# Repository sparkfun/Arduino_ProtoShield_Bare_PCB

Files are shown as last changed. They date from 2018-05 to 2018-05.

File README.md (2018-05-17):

SparkFun Arduino ProtoShield - Bare PCB
=======================================

<table class="table table-hover table-striped table-bordered">
  <tr align="center">
   <td><a href="https://cdn.sparkfun.com//assets/parts/1/1/4/1/1/13819-SparkFun_ProtoShield-01.jpg">SparkFun Arduino ProtoShield - Bare PCB</a></td>
   <td><a href="https://cdn.sparkfun.com//assets/parts/1/1/4/1/2/13820-SparkFun_ProtoShield_Kit-01.jpg">SparkFun ProtoShield Kit</a></td>
  </tr>
  <tr align="center">
    <td>SparkFun Arduino ProtoShield - Bare PCB [ <a href="https://www.sparkfun.com/products/13819">DEV-13819</a> ]</td>
    <td>SparkFun ProtoShield Kit [ <a href="https://www.sparkfun.com/products/13820">DEV-13820</a> ]</td>
  </tr>
</table>

The SparkFun Arduino ProtoShield is a bare PCB with no attached or included parts that lets you customize your own Arduino shield using whatever circuit you can come up with! You will even be able to test your circuit or project to make sure everything is working the way it should! The SparkFun Arduino ProtoShield is based off the Arduino R3’s footprint that allows you to easily incorporate it with favorite Arduino-based device.

Repository Contents
-------------------
* **/Firmware** - Example code used in the hookup guide.
* **/Hardware** - All Eagle design files (.brd, .sch)
* **/Production** - All Eagle design files (.brd, .sch)

Documentation
--------------
* **[Hookup Guide](https://learn.sparkfun.com/tutorials/sparkfun-arduino-protoshield-hookup-guide)** - Basic hookup guide for the SparkFun Arduino ProtoShield v40.
* _**[Quickstart Guide (RETIRED)](https://learn.sparkfun.com/tutorials/arduino-protoshield-quickstart-guide)** - Basic quickstart guide for the SparkFun Arduino ProtoShield v25._

Product Versions
----------------
* [DEV-13819](https://www.sparkfun.com/products/13819) - Bare pcb.
* [DEV-13820](https://www.sparkfun.com/products/13820) - Protoshield Kit. Bare pcb, plus stackable headers, indicator LEDs, push buttons, and resistors.
* _[DEV-11665 (RETIRED)](https://www.sparkfun.com/products/11665) - Bare pcb._
* _[DEV-07914 (RETIRED)](https://www.sparkfun.com/products/7914) - Protoshield Kit. Bare pcb plus stackable headers, indicator LEDs, push buttons and resistors._

Version History
---------------
* [V_4.0F2.0](https://github.com/sparkfun/Arduino_ProtoShield_Bare_PCB/releases/tag/V_4.0F2.0) - Revision v4.0 with updated example code.
* [V_2.5F1.0](https://github.com/sparkfun/Arduino_ProtoShield_Bare_PCB/releases/tag/V_2.5F1.0) - Initial release with example code from quickstart guide 
* [V_2.5](https://github.com/sparkfun/Arduino_ProtoShield_Bare_PCB/releases/tag/V_2.5) - Initial release

License Information
-------------------

This product is _**open source**_! 

Please review the LICENSE.md file for license information. 

If you have any questions or concerns on licensing, please contact techsupport@sparkfun.com.

Distributed as-is; no warranty is given.

- Your friends at SparkFun.

_<COLLABORATION CREDIT>_

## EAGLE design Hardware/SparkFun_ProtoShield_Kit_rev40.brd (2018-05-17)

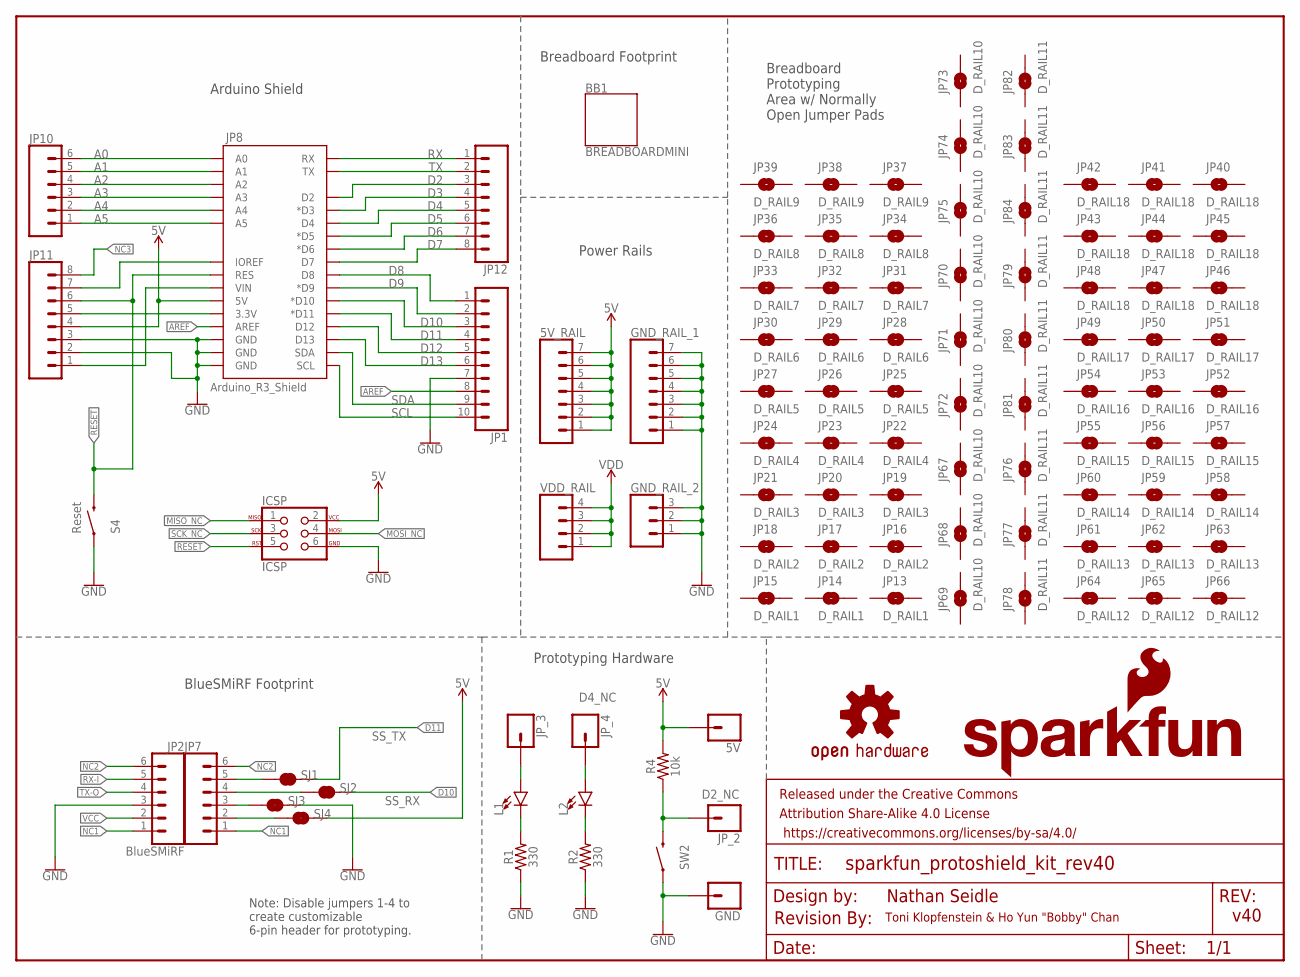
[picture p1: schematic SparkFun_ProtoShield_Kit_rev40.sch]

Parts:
5V: CONN_01; 1X01
5V_RAIL: CONN_07NO_SILK; 1X07_NO_SILK
BB1: BREADBOARDMINI; BREADBOARD-MINI
FRAME1: FRAME-LETTER; CREATIVE_COMMONS
GND: CONN_01; 1X01
GND_RAIL_1: CONN_07NO_SILK; 1X07_NO_SILK
GND_RAIL_2: CONN_031X03_NO_SILK; 1X03_NO_SILK
ICSP: ICSP; 2X3
JP1: CONN_10"; 1X10
JP2: BlueSMiRF; 1X06
JP7, JP10: CONN_06SILK_FEMALE_PTH; 1X06
JP8: ARDUINO_R3_SHIELDR3_PROTO_SHIELD; UNO_R3_PROTO_SHIELD
JP11, JP12: CONN_08"; 1X08
JP13, JP14, JP15: D_RAIL1; SMT-JUMPER_2_NO_NO-SILK
JP16, JP17, JP18: D_RAIL2; SMT-JUMPER_2_NO_NO-SILK
JP19, JP20, JP21: D_RAIL3; SMT-JUMPER_2_NO_NO-SILK
JP22, JP23, JP24: D_RAIL4; SMT-JUMPER_2_NO_NO-SILK
JP25, JP26, JP27: D_RAIL5; SMT-JUMPER_2_NO_NO-SILK
JP28, JP29, JP30: D_RAIL6; SMT-JUMPER_2_NO_NO-SILK
JP31, JP32, JP33: D_RAIL7; SMT-JUMPER_2_NO_NO-SILK
JP34, JP35, JP36: D_RAIL8; SMT-JUMPER_2_NO_NO-SILK
JP37, JP38, JP39: D_RAIL9; SMT-JUMPER_2_NO_NO-SILK
JP40, JP41, JP42, JP43, JP44, JP45, JP46, JP47, JP48: D_RAIL18; SMT-JUMPER_2_NO_NO-SILK
JP49, JP50, JP51: D_RAIL17; SMT-JUMPER_2_NO_NO-SILK
JP52, JP53, JP54: D_RAIL16; SMT-JUMPER_2_NO_NO-SILK
JP55, JP56, JP57: D_RAIL15; SMT-JUMPER_2_NO_NO-SILK
JP58, JP59, JP60: D_RAIL14; SMT-JUMPER_2_NO_NO-SILK
JP61, JP62, JP63: D_RAIL13; SMT-JUMPER_2_NO_NO-SILK
JP64, JP65, JP66: D_RAIL12; SMT-JUMPER_2_NO_NO-SILK
JP67, JP68, JP69, JP70, JP71, JP72, JP73, JP74, JP75: D_RAIL10; SMT-JUMPER_2_NO_NO-SILK
JP76, JP77, JP78, JP79, JP80, JP81, JP82, JP83, JP84: D_RAIL11; SMT-JUMPER_2_NO_NO-SILK
JP_2, JP_3, JP_4: CONN_01; 1X01
L1, L2: LED3MM; LED_3MM
LOGO1: OSHW-LOGOS; OSHW-LOGO-S
R1, R2: 330; AXIAL-0.3
R4: 10k; AXIAL-0.3
S4: MOMENTARY-SWITCH-SPST-PTH-6.0MM; TACTILE_SWITCH_PTH_6.0MM
SJ1, SJ2, SJ3, SJ4: JUMPER-SMT_2_NC_TRACE_SILK; SMT-JUMPER_2_NC_TRACE_SILK
SW2: MOMENTARY-SWITCH-SPST-PTH-6.0MM; TACTILE_SWITCH_PTH_6.0MM
U$1: SFE_LOGO_NAME_FLAME.1_INCH; SFE_LOGO_NAME_FLAME_.1
U$2: REVISION
VDD_RAIL: CONN_041X04_NO_SILK; 1X04_NO_SILK

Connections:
3.3: JP8.3.3V, JP11.5
5V: 5V.1, 5V_RAIL.1, 5V_RAIL.2, 5V_RAIL.3, 5V_RAIL.4, 5V_RAIL.5, 5V_RAIL.6, 5V_RAIL.7, ICSP.2, JP8.5V, JP11.4, R4.P$2 (2), SJ4.2
A1: JP8.A1, JP10.5
A2: JP8.A2, JP10.4
A5: JP8.A5, JP10.1
AREF: JP1.8, JP8.AREF
D2: JP8.D2, JP12.3
D2_NC: JP_2.1, R4.P$1 (1), SW2.3 (2)
D3: JP8.D3 (*D3), JP12.4
D4: JP8.D4, JP12.5
D5: JP8.D5 (*D5), JP12.6
D6: JP8.D6 (*D6), JP12.7
D7: JP8.D7, JP12.8
D8: JP1.1, JP8.D8
D9: JP1.2, JP8.D9 (*D9)
D10: JP1.3, JP8.D10 (*D10), SJ2.2
D11: JP1.4, JP8.D11 (*D11), SJ1.2
D12: JP1.5, JP8.D12
D13: JP1.6, JP8.D13
GND: GND.1, GND_RAIL_1.1, GND_RAIL_1.2, GND_RAIL_1.3, GND_RAIL_1.4, GND_RAIL_1.5, GND_RAIL_1.6, GND_RAIL_1.7, GND_RAIL_2.1, GND_RAIL_2.2, GND_RAIL_2.3, ICSP.6, JP1.7, JP2.3, JP7.3, JP8.GND@0 (GND), JP8.GND@1 (GND), JP8.GND@2 (GND), JP11.2, JP11.3, R1.P$1 (1), R2.P$1 (1), S4.1, SJ3.1, SJ3.2, SW2.1
JP3: JP_3.1, L1.A
JP4: JP_4.1, L2.A
MISO_NC: ICSP.1
MOSI_NC: ICSP.4
unnamed: JP8.IOREF, JP11.7
unnamed: JP8.A0, JP10.6
unnamed: JP8.A4, JP10.2
unnamed: JP8.A3, JP10.3
unnamed: L1.K (C), R1.P$2 (2)
unnamed: L2.K (C), R2.P$2 (2)
NC1: JP2.1, JP7.1
NC2: JP2.6, JP7.6
NC3: JP11.8
RESET: ICSP.5, JP8.RES, JP11.6, S4.3 (2)
RX: JP8.RX, JP12.1
RX-I: JP2.5, JP7.5, SJ1.1
SCK_NC: ICSP.3
SCL: JP1.10, JP8.SCL
SDA: JP1.9, JP8.SDA
TX: JP8.TX, JP12.2
TX-O: JP2.4, JP7.4, SJ2.1
VCC: JP2.2, JP7.2, SJ4.1
VDD: VDD_RAIL.1, VDD_RAIL.2, VDD_RAIL.3, VDD_RAIL.4
VIN: JP8.VIN, JP11.1

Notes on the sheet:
Nathan Seidle
v40
Toni Klopfenstein & Ho Yun "Bobby" Chan
Arduino Shield
Power Rails
Prototyping Hardware
Breadboard Footprint
BlueSMiRF Footprint
Note: Disable jumpers 1-4 to create customizable 6-pin header for prototyping.
Arduino_R3_Shield
Reset
SS_TX
SS_RX
Breadboard Prototyping Area w/ Normally Open Jumper Pads
D4_NC

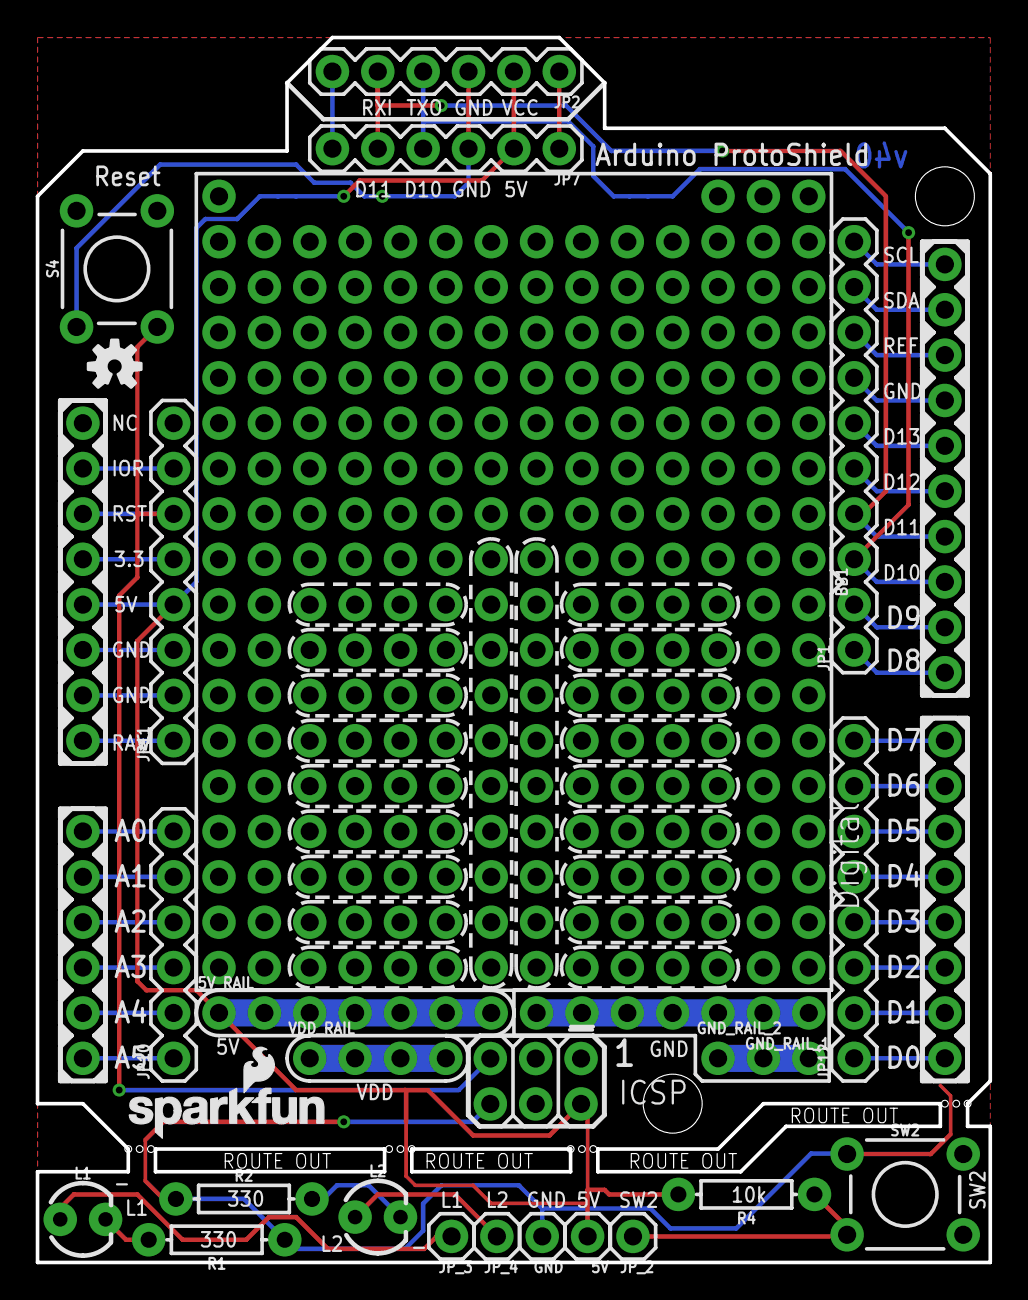
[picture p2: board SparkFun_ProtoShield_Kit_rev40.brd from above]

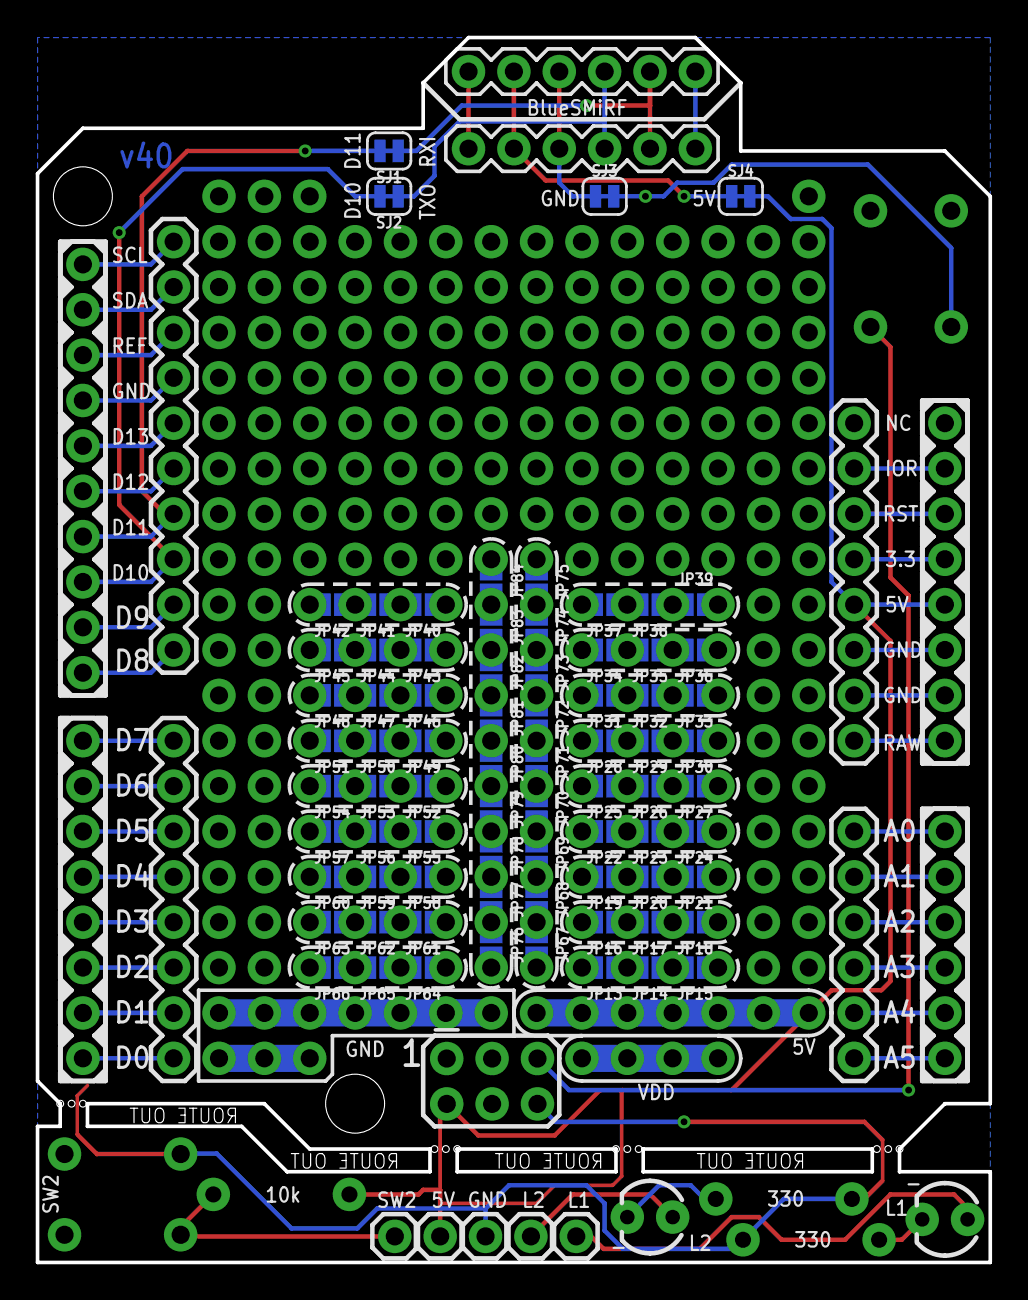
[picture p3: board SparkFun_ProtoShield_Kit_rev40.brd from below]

Board: 2 copper layers, 53.3 x 68.6 mm, 105 parts (76 on the bottom side), 40 nets.

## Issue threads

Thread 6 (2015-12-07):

"DRILL OUT" note

SFE-KADE, 2015-12-07:
With interior milling work we've found it's best to use the phrase "ROUTE OUT" for notes and to put it on the dimension layer instead of tDocu so it ends up in the gerbers.

ToniCorinne, 2016-02-08:
Updated to 'ROUTE OUT'. I kept it on tDocu, but also added a copy to Dimensions.

Closed 2016-02-08.

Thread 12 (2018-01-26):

Double check v32

edspark, 2018-01-26:
The product needs the version number in the bottom copper layer somewhere on the PCB.

bboyho, 2018-01-27:
Hmm, v32 should be on the upper left corner above SCL on the back of the board. =)

edspark, 2018-01-29:
Non-issue, closing!

Closed 2018-01-29.

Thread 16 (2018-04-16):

Double check v40

edspark, 2018-04-16:
1) Is the version number correct? [NO]
comment: Change to v40.

2) Is there a correct version number in the copper (aligned properly with the edge of the PCB)? [NO]
comment: Change to v40.

Everything looked good but since the revision is going to REDs, it's time to change the version number on both schematic and PCB!

bboyho, 2018-04-16:
@edspark

I updated the schematic and board to say v40. I also updated the file names. =)

[https://github.com/sparkfun/Arduino_ProtoShield_Bare_PCB/pull/17](https://github.com/sparkfun/Arduino_ProtoShield_Bare_PCB/pull/17)

Closed 2018-04-16.

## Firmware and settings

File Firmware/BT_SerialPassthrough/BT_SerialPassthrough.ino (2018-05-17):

/*
  Example Bluetooth Serial Passthrough Sketch
  modified by: Ho Yun "Bobby" Chan
  date: May 17, 2018
  by: Jim Lindblom
  date: February 26, 2013
  SparkFun Electronics
  license: Public domain

  This example sketch converts an RN-42 bluetooth module to
  communicate at 9600 bps (from 115200), and passes any serial
  data between Serial Monitor and bluetooth module.
****************************************************************/

#include <SoftwareSerial.h>

int bluetoothTx = 10;  // TX-O pin of bluetooth mate, Arduino D10
int bluetoothRx = 11;  // RX-I pin of bluetooth mate, Arduino D11

SoftwareSerial bluetooth(bluetoothTx, bluetoothRx);// (Arduino SS_RX = pin 10, Arduino SS_TX = pin 11)

void setup()
{
  Serial.begin(9600);  // Begin the serial monitor at 9600bps

  bluetooth.begin(115200);  // The Bluetooth Mate defaults to 115200bps
  bluetooth.print("$");  // Print three times individually
  bluetooth.print("$");
  bluetooth.print("$");  // Enter command mode
  delay(100);  // Short delay, wait for the Mate to send back CMD
  bluetooth.println("U,9600,N");  // Temporarily Change the baudrate to 9600, no parity
  // 115200 can be too fast at times for NewSoftSerial to relay the data reliably
  bluetooth.begin(9600);  // Start bluetooth serial at 9600
}

void loop()
{
  if (bluetooth.available()) // If the bluetooth sent any characters
  {
    // Send any characters the bluetooth prints to the serial monitor
    Serial.print((char)bluetooth.read());
  }
  if (Serial.available()) // If stuff was typed in the serial monitor
  {
    // Send any characters the Serial monitor prints to the bluetooth
    bluetooth.print((char)Serial.read());
  }
  // and loop forever and ever!
}

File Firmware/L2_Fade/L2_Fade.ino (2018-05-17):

/* Fading LED

  Use for-loops to smoothly vary the brightness of an LED

  This sketch was written by SparkFun Electronics,
  with lots of help from the Arduino community.
  This example is based on the Fading LEDs example
  in the LilyPad Development Board Activity Guide.

  This code is completely free for any use.
  Visit https://learn.sparkfun.com/tutorials/lilypad-development-board-activity-guide/4-fading-leds
  for more information
  Visit http://www.arduino.cc to learn about the Arduino.

******************************************************************************/

// Create integer variable for the LED pin we'll be using:
const int L2 = 6;

// Create a new integer variable called brightness:
int brightness;

void setup()
{
  // Set the LED pins to be output:
  pinMode(L2, OUTPUT);
}

void loop()
{
  // The two "for loops" below will make a LED fade on and off in a "breathing" pattern.

  // Now we'll have the program automatically change the value of brightness
  // using a command called "for".

  // for is like a tiny version of loop. The for command has several parts:
  // 1. something to do before starting (brightness = 0)
  // 2. a test to decide whether to keep going (brightness <= 255)
  // 3. a block of commands to run (everything within the {} below the for)
  // 4. a command to run before doing it again (brightness = brightness + 1)

  // Here's a for command which will start brightness at 0, check to see if it's less than
  // or equal to 255, run the commands after it, then add one to brightness and start over:

  for (brightness = 0; brightness <= 255; brightness = brightness + 1)
  {
    // Within the loop, we'll use brightness variable to control the brightness of the LEDs:

    analogWrite(L2, brightness);

    // NOTE that not all pins work with analogWrite!
    // The ones with a "~" in front of them will change brightness,
    // the others will only turn on if brightness > 128.
    // Both types are used above, run the code and note the difference between them.

    // The delay command controls the speed - if you make the delay larger,
    // it will slow down the loop. Smaller, and it will run faster:

    delay(5);
  }

  // What if we want the LED to start at full brightness and fade to black?
  // We can easily set up the for loop to run in reverse:

  for (brightness = 255; brightness >= 0; brightness = brightness - 1)
  {
    analogWrite(L2, brightness);
    delay(5);
  }
}

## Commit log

2015-05-04 Adding hardware files, updating readme
    [SparkFun_ProtoShield_Kit.brd, SparkFun_ProtoShield_Kit.sch]
2015-09-02 WIP - basic hardware layout changes
    [SparkFun_ProtoShield_Kit.brd, SparkFun_ProtoShield_Kit.sch]
2015-09-03 Ready for engineering review
    [SparkFun_ProtoShield_Kit.brd, SparkFun_ProtoShield_Kit.sch]
2015-09-15 Fixing part names, adding additional connector from engineering review
    [SparkFun_ProtoShield_Kit.brd, SparkFun_ProtoShield_Kit.sch]
2015-09-29 Updates from engineering review
    [SparkFun_ProtoShield_Kit.brd, SparkFun_ProtoShield_Kit.sch]
2015-12-02 WIP-bumping annular rings
    [SparkFun_ProtoShield_Kit.brd, SparkFun_ProtoShield_Kit.sch]
2015-12-03 Updates from checklist
    [SparkFun_ProtoShield_Kit.brd, SparkFun_ProtoShield_Kit.sch]
2016-02-08 Fixing QC checks on silk labels, ROUTE OUT note
    [SparkFun_ProtoShield_Kit.brd, SparkFun_ProtoShield_Kit.sch]
2017-10-31 Add files via upload
    -updated labels and silkscreen
    -changed names to vectors
    -flipped the BlueSMiRF header's orientation so that the bluetooth faces out away from the board
    -modified traces for the BlueSMiRF
    [SparkFun_ProtoShield_Kit.brd, SparkFun_ProtoShield_Kit.sch]
2017-11-02 Update files
    **Board**
    * Align the 5V/GND silk screen.
    * Replace the SparkFun logo with a SparkFun logo w/flame, in the SparkFun Aesthetics library.
    * Add the silk for the Arduino PTH headers on the bottom side as well.
    * Fix placement and size of the BlueSMiRF text on the underside of the shield.
    * Add silkscreen for the UART pins for BlueSMiRF.
    * Add copper boundary around GND trace so that it can be easily cut.
    * Adjust position of prototyping hardware header.
    **Schematic**
    * Change all text to “vector”.
    * Change the labels for the various boxes so they are the same ratio and size.
    * Change all dashed lines to “Short Dash”.
    * Update all outdated packages to ou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
    [SparkFun_ProtoShield_Kit.brd, SparkFun_ProtoShield_Kit.sch]
2017-11-02 Update file name to reflect revision
    [SparkFun_ProtoShield_Kit_rev31.brd]
2017-11-02 Update File Name
    [SparkFun_ProtoShield_Kit_rev31.sch]
2017-11-06 Add files via upload
    * Change wire boundary to bRestrict layer to prevent ground pour from creating a thermal around GND jumper pads.
    * Move OSHW logo next to SparkFun logo
    * Move schematic components around to make use of the empty space
    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
    [SparkFun_ProtoShield_Kit_rev31.brd, SparkFun_ProtoShield_Kit_rev31.sch]
2017-11-07 Add files via upload
    Add more tRestrict and bRestrict boundaries so that ground pours do not connect to GND pin after jumper.
2018-01-24 Update_Proto2
    -Shifted the mini-breadboard footprint
    -Moved Vcc and GND rails to bottom for access
    -Added VDD as an option
    -Added Disconnected Breadboard rails based on Jim’s Design (GPS Shield), best of both worlds
    -Add 2x more through hole pins for prototyping area
    -Shifted Prototyping Hardware Around
    -Switch Hardware Serial to Software -Serial to prevent bricking UART device
    -Added Vcc and GND traces through mouse bite just in case
    -Adjusted Header D8-SCL so that the shield can stack with a breadboard (Michelle’s Suggestion)
    -Added little bit more silkscreen to distinguish location of stackable headers
    -Moved Reset button up for better access
    -Switched Momentary Push Button Package t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
    [SparkFun_ProtoShield_Kit_rev32.brd, SparkFun_ProtoShield_Kit_rev32.sch]
2018-02-05 Proto 2 QC Update
    -Adjust normally open (NO) jumper pad rails so the silkscreen is not over the vias to prevent errors.
    -Adjust the "+" 5V trace intersection for the prototyping hardware.
    [SparkFun_ProtoShield_Kit_rev32.brd, SparkFun_ProtoShield_Kit_rev32.sch]
2018-02-06 Airwires
    -Fix airwires on analog pins, 5V rail, and VDD rail.
    -Fix tiny floating net wire in schematic.
    [SparkFun_ProtoShield_Kit_rev32.brd, SparkFun_ProtoShield_Kit_rev32.sch]
2018-04-14 Update Dimensions
    - Update dimensions (layer 47) in Eagle file for x and y instead of having it for the chamfered measurements.
    - Add dimensions between mounting hole's center and the edge of board
    [SparkFun_ProtoShield_Kit_rev32.brd]
2018-04-16 Update to v40
    -Update SCH version number
    -Update BRD version number in copper
    -Update file names
    [SparkFun_ProtoShield_Kit_rev40.brd, SparkFun_ProtoShield_Kit_rev40.sch]
2018-04-18 created v40 board
    [SparkFun_ProtoShield_Kit_rev40.brd, SparkFun_ProtoShield_Kit_rev40.sch]
2018-05-17 Remove Old Example Code
    Since the old example code is saved in the old tutorial and tagged in the GitHub repo, I am removing it from the current master.

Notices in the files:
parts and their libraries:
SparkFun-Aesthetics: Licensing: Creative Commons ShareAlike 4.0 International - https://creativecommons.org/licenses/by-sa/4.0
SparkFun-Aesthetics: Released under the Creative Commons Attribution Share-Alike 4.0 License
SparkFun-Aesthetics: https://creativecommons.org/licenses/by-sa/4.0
